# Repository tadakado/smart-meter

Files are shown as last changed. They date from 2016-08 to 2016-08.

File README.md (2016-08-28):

# Smart meter board by ADE7816

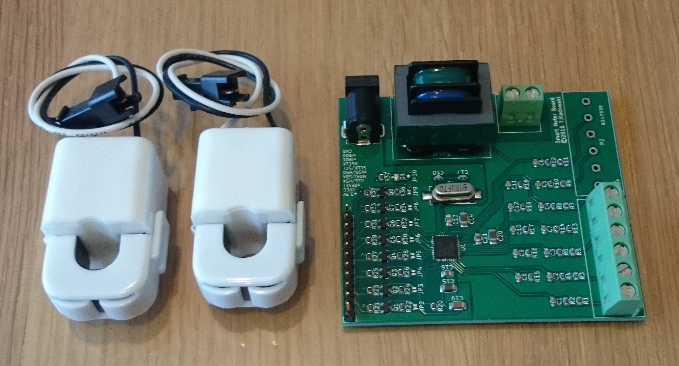
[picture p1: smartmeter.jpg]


## Description (in Japanese)
アナログデバイスのADE7816を用いた電力計のプロトタイプで、最大6チャンネルの測定ができます。
ここには、回路図、基板デザイン、テスト用のプログラムコードが含まれます。

## Description
This is a design of smart meter prototype.
The board can monitor 6 channels independently utilizing Analog Device ADE7816.
This repository includes a set of circuit/breatboard design and example software code.

## Contents in folders
* KiCad : Smart meter board
* Soft  : Javascript examples to control the smart meter board (with Intel Edison)
* FPGA  : Raw level data capture function for the smart meter board (Under development)

## Pin assignments of the board for communicating with an external cpu board
| Pin | Description |
| --- | --- |
| 3.3V | 3.3V input for the board |
| LVCC | Reference VCC of cpu board (could be 1.8V) |
| nRESET | Reset ADE7816 (active low) |
| nSS/HSA  | Select input for SPI / Port active output for HSDC (active low) |
| MOSI/SDA | Data input for SPI / Data inout for I2C |
| MISO/HSD | Data output for SPI / Data output for HSDC |
| SCLK/SCL | Clock input for SPI / Clock input for I2C |
| HSCLK | Clock output for HSDC |
| nIRQ1 | Interrupt request output (active low) |
| nIRQ0 | Interrupt request output (active low) |
| GND | Ground |

Note: LVCC is designed for a cpu board system with lower voltage such as 1.8V.
If you use 3.3V system, you can skip level converters.
For such case, use JP2-9 and remove R21-36 & Q1-8.

## Protocols of the interface
You can chose I2C or SPI to control ADE7816.
HSDC is for capturing raw level data, such as AC voltage and currents.
Due to the pin assignment, I2C and HSDC works together.
For more details, see the AD7816 manual.

## Sensor devices
Voltage and current sensing trans used in the board are
* VT2401-A01 http://growwill.co.jp/products/ep/trans/vt/#vt2401-a01
* CTL-10-CLS http://www.u-rd.com/products/CTL-10-CLS.html

If you use another sensors, you may change values of resistors.

----------
CC BY 4.0 Tadashi Kadowaki (tadakado@gmail.com)  
Licensed under a Creative Commons Attribution 4.0  
https://creativecommons.org/licenses/by/4.0/

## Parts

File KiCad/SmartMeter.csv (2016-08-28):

Reference | Value | Footprint | Datasheet
C18 | 20pF | Capacitors_SMD:C_0603_HandSoldering
C17 | 20pF | Capacitors_SMD:C_0603_HandSoldering
C21 | 0.1uF | Capacitors_SMD:C_0805_HandSoldering
C20 | 4.7uF | Capacitors_SMD:C_1206_HandSoldering
C11 | 0.22uF | Capacitors_SMD:C_0805_HandSoldering
C16 | 0.22uF | Capacitors_SMD:C_0805_HandSoldering
C15 | 4.7uF | Capacitors_SMD:C_1206_HandSoldering
C19 | 1uF | Capacitors_SMD:C_1206_HandSoldering
R20 | 10K | Resistors_SMD:R_0805_HandSoldering
Y1 | 16.384MHz | Crystals_Oscillators_SMD:Q_49U3HMS
R19 | 1K | Resistors_SMD:R_0805_HandSoldering
C14 | 22nF | Capacitors_SMD:C_0603_HandSoldering
R18 | 1K | Resistors_SMD:R_0805_HandSoldering
C12 | 22nF | Capacitors_SMD:C_0603_HandSoldering
R17 | 1K | Resistors_SMD:R_0805_HandSoldering
C10 | 22nF | Capacitors_SMD:C_0603_HandSoldering
R16 | 1K | Resistors_SMD:R_0805_HandSoldering
C9 | 22nF | Capacitors_SMD:C_0603_HandSoldering
R15 | 1K | Resistors_SMD:R_0805_HandSoldering
C8 | 22nF | Capacitors_SMD:C_0603_HandSoldering
R7 | 1K | Resistors_SMD:R_0805_HandSoldering
C1 | 22nF | Capacitors_SMD:C_0603_HandSoldering
R13 | 1K | Resistors_SMD:R_0805_HandSoldering
C7 | 22nF | Capacitors_SMD:C_0603_HandSoldering
R14 | 100 | Resistors_SMD:R_0805_HandSoldering
R1 | 33 | Resistors_SMD:R_0805_HandSoldering
R8 | 1K | Resistors_SMD:R_0805_HandSoldering
C2 | 22nF | Capacitors_SMD:C_0603_HandSoldering
R9 | 1K | Resistors_SMD:R_0805_HandSoldering
C3 | 22nF | Capacitors_SMD:C_0603_HandSoldering
R10 | 1K | Resistors_SMD:R_0805_HandSoldering
C4 | 22nF | Capacitors_SMD:C_0603_HandSoldering
R11 | 1K | Resistors_SMD:R_0805_HandSoldering
C5 | 22nF | Capacitors_SMD:C_0603_HandSoldering
R12 | 1K | Resistors_SMD:R_0805_HandSoldering
C6 | 22nF | Capacitors_SMD:C_0603_HandSoldering
T1 | TRANSFO | ADE7816:VT2401-A01
JP1 | Jumper_NC_Small | ADE7816:JP
P1 | CONN_01X06 | ADE7816:XW4E-06C1-S1
R2 | 33 | Resistors_SMD:R_0805_HandSoldering
R3 | 33 | Resistors_SMD:R_0805_HandSoldering
R4 | 33 | Resistors_SMD:R_0805_HandSoldering
R5 | 33 | Resistors_SMD:R_0805_HandSoldering
R6 | 33 | Resistors_SMD:R_0805_HandSoldering
P2 | CONN_01X06 | ADE7816:XW4E-06C1-S1
P3 | CONN_01X02 | ADE7816:XW4E-02C1-S1
C13 | 4.7uF | Capacitors_SMD:C_1206_HandSoldering
U1 | ADE7816 | ADE7816:QFN-40-1EP_6x6mm_Pitch0.5mm_HandSoldering | DOCUMENTATION
P4 | HEAT SINK | Wire_Pads:SolderWirePad_single_1-2mmDrill
P7 | Power
CON1 | BARREL_JACK
P5 | SPI
P6 | Extra
Q1 | BSS138 | SOT-23
R21 | 10K
R26 | 10K
Q2 | BSS138 | SOT-23
R22 | 10K
R27 | 10K
Q3 | BSS138 | SOT-23
R23 | 10K
R28 | 10K
Q4 | BSS138 | SOT-23
R24 | 10K
R29 | 10K
Q5 | BSS138 | SOT-23
R25 | 10K
R30 | 10K
JP2 | Jumper_NO_Small
JP3 | Jumper_NO_Small
JP4 | Jumper_NO_Small
JP5 | Jumper_NO_Small
JP6 | Jumper_NO_Small

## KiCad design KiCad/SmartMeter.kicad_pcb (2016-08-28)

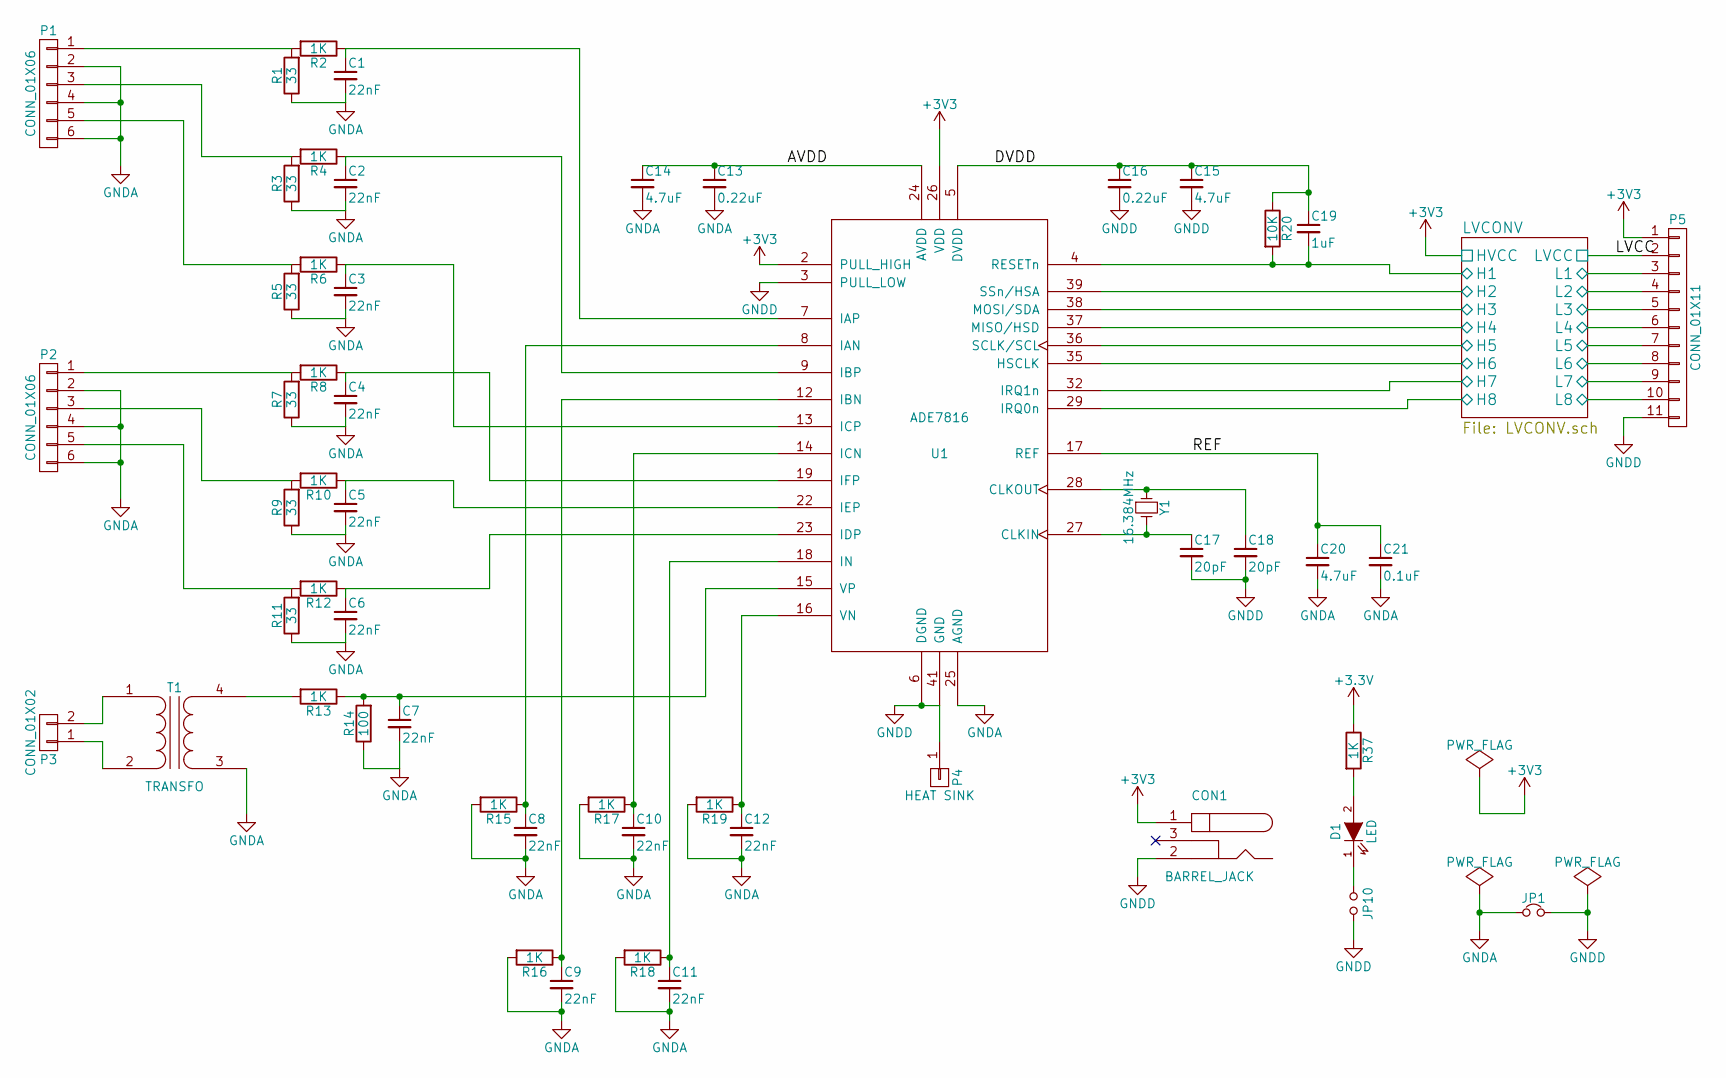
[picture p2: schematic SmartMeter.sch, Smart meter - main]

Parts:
C1, C2, C3, C4, C5, C6, C7, C8, C9, C10, C11, C12: 22nF; C_0603
C13, C16: 0.22uF; C_0805
C14, C15, C20: 4.7uF; C_1206
C17, C18: 20pF; C_0603
C19: 1uF; C_1206
C21: 0.1uF; C_0805
CON1: BARREL_JACK; DC-Jack
D1: LED; LED-0603
JP1: Jumper_NC_Small; Jumper_Close
JP10: Jumper_NO_Small; Jumper
P1, P2: CONN_01X06; XW4E-06C1-S1
P3: CONN_01X02; XW4E-02C1-S1
P4: HEAT SINK; SolderWirePad_single_1-2mmDrill
P5: CONN_01X11; Pin_Header_Straight_1x11
R1, R3, R5, R7, R9, R11: 33; R_0603
R2, R4, R6, R8, R10, R12, R13, R15, R16, R17, R18, R19, R37: 1K; R_0603
R14: 100; R_0603
R20: 10K; R_0603
T1: TRANSFO; VT2401-A01
U1: ADE7816; QFN-40-1EP_6x6mm_Pitch0.5mm
Y1: 16.384MHz; Q_49U3HMS

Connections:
+3V3: CON1.1, P5.1, R37.1, U1.2 (PULL_HIGH), U1.26 (VDD); also elsewhere on the board
/AVDD: C13.1, C14.1, U1.24 (AVDD)
/DVDD: C15.1, C16.1, C19.1, R20.1, U1.5 (DVDD)
/LVCONV/H1: C19.2, R20.2, U1.4 (RESETn); also elsewhere on the board
/LVCONV/H2: U1.39 (SSn/HSA); also elsewhere on the board
/LVCONV/H3: U1.38 (MOSI/SDA); also elsewhere on the board
/LVCONV/H4: U1.37 (MISO/HSD); also elsewhere on the board
/LVCONV/H5: U1.36 (SCLK/SCL); also elsewhere on the board
/LVCONV/H6: U1.35 (HSCLK); also elsewhere on the board
/LVCONV/H7: U1.32 (IRQ1n); also elsewhere on the board
/LVCONV/H8: U1.29 (IRQ0n); also elsewhere on the board
/LVCONV/L1: P5.3; also elsewhere on the board
/LVCONV/L2: P5.4; also elsewhere on the board
/LVCONV/L3: P5.5; also elsewhere on the board
/LVCONV/L4: P5.6; also elsewhere on the board
/LVCONV/L5: P5.7; also elsewhere on the board
/LVCONV/L6: P5.8; also elsewhere on the board
/LVCONV/L7: P5.9; also elsewhere on the board
/LVCONV/L8: P5.10; also elsewhere on the board
/LVCONV/LVCC: P5.2; also elsewhere on the board
/REF: C20.1, C21.1, U1.17 (REF)
GNDA: C1.2, C2.2, C3.2, C4.2, C5.2, C6.2, C7.2, C8.2, C9.2, C10.2, C11.2, C12.2, C13.2, C14.2, C20.2, C21.2, JP1.1, P1.2, P1.4, P1.6, P2.2, P2.4, P2.6, R1.1, R3.1, R5.1, R7.1, R9.1, R11.1, R14.1, R15.2, R16.2, R17.2, R18.2, R19.2, T1.3 (SA), U1.25 (AGND)
GNDD: C15.2, C16.2, C17.2, C18.2, CON1.2, JP1.2, JP10.2, P4.1, P5.11, U1.3 (PULL_LOW), U1.6 (DGND), U1.41 (GND)
unnamed: C1.1, R2.1, U1.7 (IAP)
unnamed: C2.1, R4.1, U1.9 (IBP)
unnamed: C3.1, R6.1, U1.13 (ICP)
unnamed: C4.1, R8.1, U1.19 (IFP)
unnamed: C5.1, R10.1, U1.22 (IEP)
unnamed: C6.1, R12.1, U1.23 (IDP)
unnamed: C7.1, R13.1, R14.2, U1.15 (VP)
unnamed: C8.1, R15.1, U1.8 (IAN)
unnamed: C9.1, R16.1, U1.12 (IBN)
unnamed: C10.1, R17.1, U1.14 (ICN)
unnamed: C11.1, R18.1, U1.18 (IN)
unnamed: C12.1, R19.1, U1.16 (VN)
unnamed: C17.1, U1.27 (CLKIN), Y1.2
unnamed: C18.1, U1.28 (CLKOUT), Y1.1
unnamed: D1.1 (K), JP10.1
unnamed: D1.2 (A), R37.2
unnamed: P1.1, R1.2, R2.2
unnamed: P1.3, R3.2, R4.2
unnamed: P1.5, R5.2, R6.2
unnamed: P2.1, R7.2, R8.2
unnamed: P2.3, R9.2, R10.2
unnamed: P2.5, R11.2, R12.2
unnamed: P3.1, T1.2 (AB)
unnamed: P3.2, T1.1 (AA)
unnamed: R13.2, T1.4 (SB)

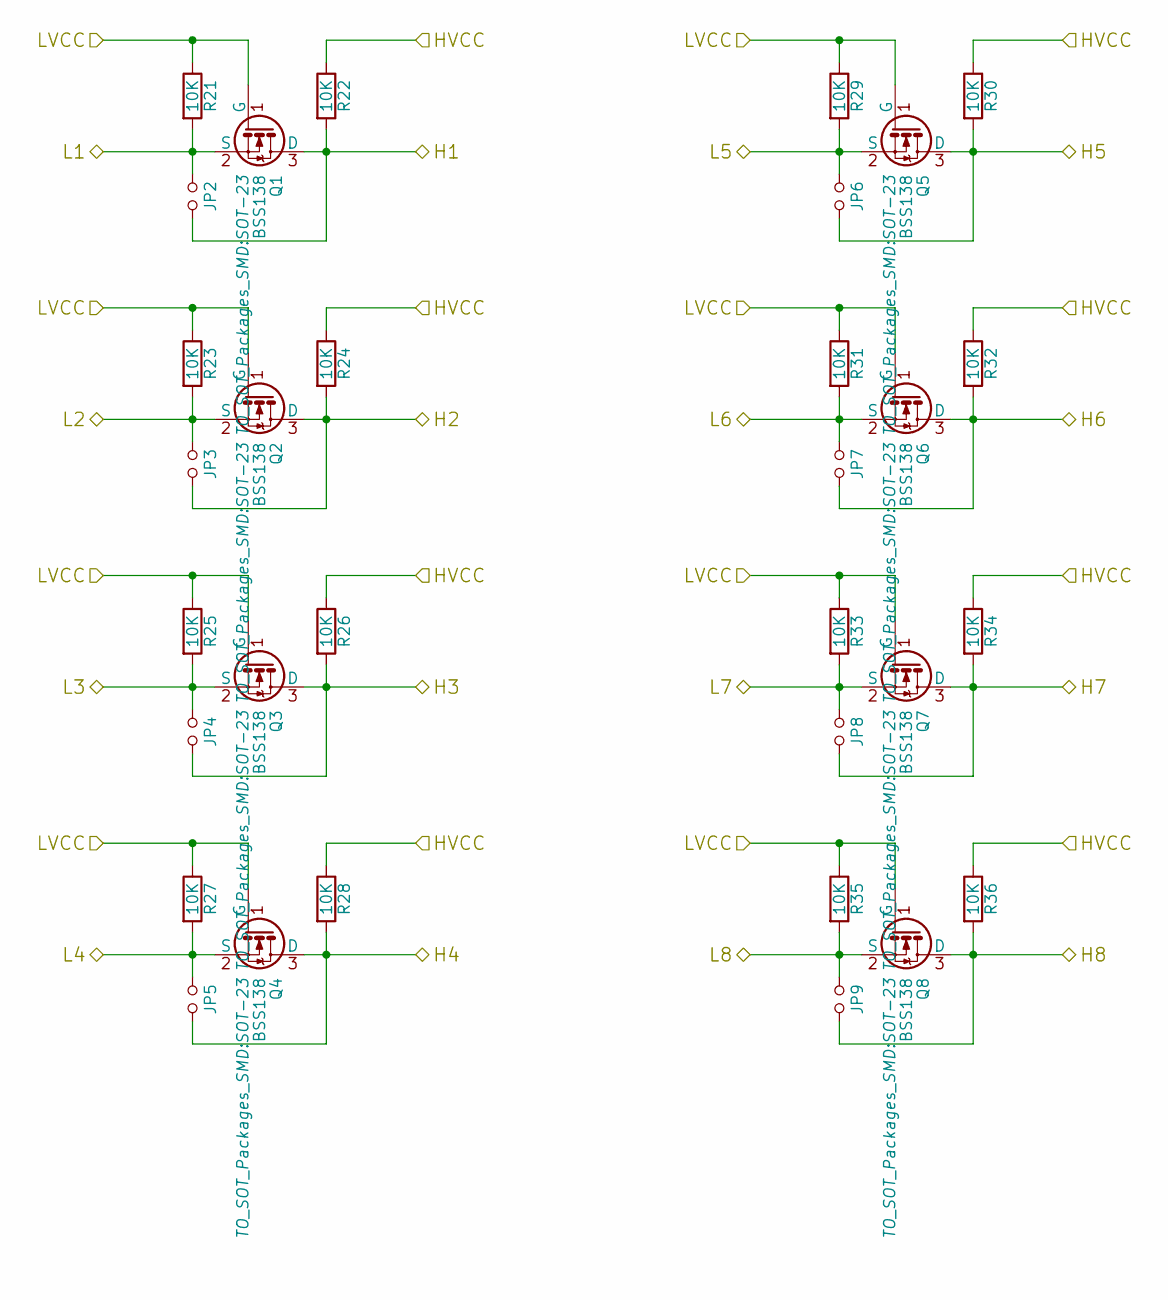
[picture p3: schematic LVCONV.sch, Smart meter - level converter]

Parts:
JP2, JP3, JP4, JP5, JP6, JP7, JP8, JP9: Jumper_NO_Small; Jumper
Q1, Q2, Q3, Q4, Q5, Q6, Q7, Q8: BSS138; SOT-23
R21, R22, R23, R24, R25, R26, R27, R28, R29, R30, R31, R32, R33, R34, R35, R36: 10K; R_0603

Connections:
+3V3: R22.1, R24.1, R26.1, R28.1, R30.1, R32.1, R34.1, R36.1; also elsewhere on the board
/LVCONV/H1: JP2.2, Q1.3 (D), R22.2; also elsewhere on the board
/LVCONV/H2: JP3.2, Q2.3 (D), R24.2; also elsewhere on the board
/LVCONV/H3: JP4.2, Q3.3 (D), R26.2; also elsewhere on the board
/LVCONV/H4: JP5.2, Q4.3 (D), R28.2; also elsewhere on the board
/LVCONV/H5: JP6.2, Q5.3 (D), R30.2; also elsewhere on the board
/LVCONV/H6: JP7.2, Q6.3 (D), R32.2; also elsewhere on the board
/LVCONV/H7: JP8.2, Q7.3 (D), R34.2; also elsewhere on the board
/LVCONV/H8: JP9.2, Q8.3 (D), R36.2; also elsewhere on the board
/LVCONV/L1: JP2.1, Q1.2 (S), R21.2; also elsewhere on the board
/LVCONV/L2: JP3.1, Q2.2 (S), R23.2; also elsewhere on the board
/LVCONV/L3: JP4.1, Q3.2 (S), R25.2; also elsewhere on the board
/LVCONV/L4: JP5.1, Q4.2 (S), R27.2; also elsewhere on the board
/LVCONV/L5: JP6.1, Q5.2 (S), R29.2; also elsewhere on the board
/LVCONV/L6: JP7.1, Q6.2 (S), R31.2; also elsewhere on the board
/LVCONV/L7: JP8.1, Q7.2 (S), R33.2; also elsewhere on the board
/LVCONV/L8: JP9.1, Q8.2 (S), R35.2; also elsewhere on the board
/LVCONV/LVCC: Q1.1 (G), Q2.1 (G), Q3.1 (G), Q4.1 (G), Q5.1 (G), Q6.1 (G), Q7.1 (G), Q8.1 (G), R21.1, R23.1, R25.1, R27.1, R29.1, R31.1, R33.1, R35.1; also elsewhere on the board

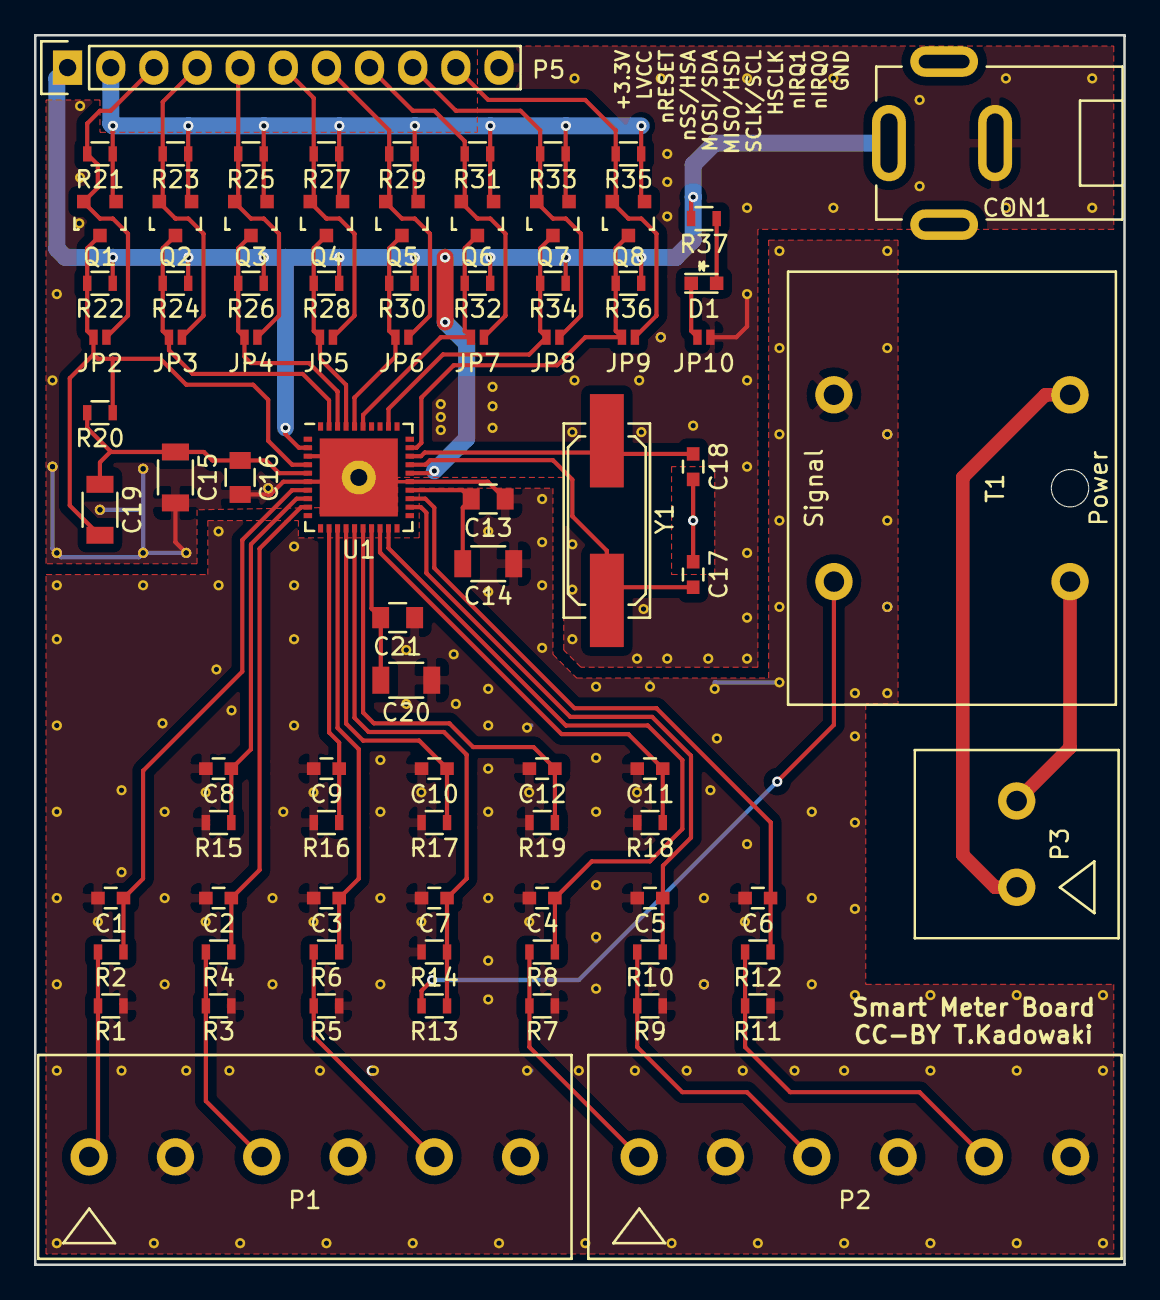
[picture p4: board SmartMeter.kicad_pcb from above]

Board: 2 copper layers, 64.1 x 72.4 mm, 86 parts (0 on the bottom side), 48 nets.

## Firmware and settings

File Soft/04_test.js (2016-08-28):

//!/usr/bin/node

// POWER UP THE ADE7816 (SEE POWER AND GROUND SECTION)

// SET AND LOCK COMMUNICATION MODE (SEE COMMUNICATION SECTION)

// WRITE REQUIRED REGISTER DEFAULTS
// WTHR1 = 0x000002
// WTHR0 = 0x000000
// VARTHR1 = 0x000002
// VARTHR0 = 0x000000
// PCF_A_COEFF = 0x400CA4 (50Hz)
// PCF_B_COEFF = 0x400CA4 (50Hz)
// PCF_C_COEFF = 0x400CA4 (50Hz)
// PCF_D_COEFF = 0x400CA4 (50Hz)
// PCF_E_COEFF = 0x400CA4 (50Hz)
// PCF_F_COEFF = 0x400CA4 (50Hz)
// DICOEFF = 0xFFF8000

// CONFIGURE METER SPECIFIC INTERRUPTS, POWER QUALITY FEATURES, AND CALIBRATE
// (SEE THE INTERRUPTS, POWER QUALITY FEATURES, AND ENERGY CALIBRATION SECTIONS)

// NOTE THAT THE FINAL REGISTER SHOULD BE WRITTEN 3 TIMES TO CLEAR THE BUFFER
// (SEE STARTING AND STOPPING THE DSP SECTION)

// ENABLE THE ENERGY METERING DSP (SEE STARTING AND STOPPING THE DSP SECTION)

const VGAIN = 0x4380
const IAGAIN = 0x4381
const IBGAIN = 0x4382
const ICGAIN = 0x4383
const IDGAIN = 0x4384
const IEGAIN = 0x4385
const IFGAIN = 0x4386
const DICOEFF = 0x4388
const HPFDIS = 0x4389
const VRMSOS = 0x438A
const IARMSOS = 0x438B
const IBRMSOS = 0x438C
const ICRMSOS = 0x438D
const IDRMSOS = 0x438E
const IERMSOS = 0x438F
const IFRMSOS = 0x4390
const AWGAIN = 0x4391
const AWATTOS = 0x4392
const BWGAIN = 0x4393
const BWATTOS = 0x4394
const CWGAIN = 0x4395
const CWATTOS = 0x4396
const DWGAIN = 0x4397
const DWATTOS = 0x4398
const EWGAIN = 0x4399
const EWATTOS = 0x439A
const FWGAIN = 0x439B
const FWATTOS = 0x439C
const AVARGAIN = 0x439D
const AVAROS = 0x439E
const BVARGAIN = 0x439F
const BVAROS = 0x43A0
const CVARGAIN = 0x43A1
const CVAROS = 0x43A2
const DVARGAIN = 0x43A3
const DVAROS = 0x43A4
const EVARGAIN = 0x43A5
const EVAROS = 0x43A6
const FVARGAIN = 0x43A7
const FVAROS = 0x43A8
const WTHR1 = 0x43AB
const WTHR0 = 0x43AC
const VARTHR1 = 0x43AD
const VARTHR0 = 0x43AE
const APNOLOAD = 0x43AF

const VARNOLOAD = 0x43B0
const PCF_A_COEFF = 0x43B1
const PCF_B_COEFF  = 0x43B2
const PCF_C_COEFF  = 0x43B3
const PCF_D_COEFF  = 0x43B4
const PCF_E_COEFF  = 0x43B5
const PCF_F_COEFF  = 0x43B6
const VRMS = 0x43C0
const IARMS = 0x43C1
const IBRMS = 0x43C2
const ICRMS = 0x43C3
const IDRMS = 0x43C4
const IERMS = 0x43C5
const IFRMS  = 0x43C6

const RUN = 0xE228

const AWATTHR = 0xE400
const BWATTHR = 0xE401
const CWATTHR = 0xE402
const DWATTHR = 0xE403
const EWATTHR = 0xE404
const FWATTHR = 0xE405
const AVARHR = 0xE406
const BVARHR = 0xE407
const CVARHR = 0xE408
const DVARHR = 0xE409
const EVARHR = 0xE40A
const FVARHR = 0xE40B

const VPEAK = 0xE501
const STATUS0 = 0xE502
const STATUS1 = 0xE503
const OILVL = 0xE507
const OVLVL = 0xE508
const SAGLVL = 0xE509
const MASK0 = 0xE50A
const MASK1 = 0xE50B
const IAWV_IDWV = 0xE50C
const IBWV_IEWV = 0xE50D
const ICWV_IFWV = 0xE50E
const VWV = 0xE510
const CHECKSUM = 0xE51F
const CHSTATUS = 0xE600
const ANGLE0 = 0xE601
const ANGLE1 = 0xE602
const ANGLE2 = 0xE603
const PERIOD = 0xE607
const CHNOLOAD = 0xE608
const LINECYC = 0xE60C
const ZXTOUT = 0xE60D
const COMPMODE = 0xE60E
const GAIN = 0xE60F
const CHSIGN = 0xE617
const CONFIG = 0xE618
const MMODE = 0xE700
const ACCMODE = 0xE701
const LCYCMODE = 0xE702
const PEAKCYC = 0xE703
const SAGCYC = 0xE704
const HSDC_CFG = 0xE706
const VERSION  = 0xE707
const SPISELECT = 0xEBFF
const CONFIG2  = 0xEC01

function parseBytes(v, n, p) {
  var a = new Array(n)
  for(var i = 1; i <= n; i++) {
    var shift = (i-1) * 8
    a[n-i] = (v >>> shift) & 0xFF
  }
  // padding 'ZPSE' or 'SE' for 24 bit registers with 32 bit communication
  if (n == 4 && p == 'ZPSE' && a[1] & 0x80) a[0] = 0x0F
  if (n == 4 && p == 'SE' && a[1] & 0x80) a[0] = 0xFF
  return a
}

function i2cWriteSeq(addr, buf) {
  var a = new Array(parseBytes(addr, 2), buf)
  return Buffer(Array.prototype.concat.apply([], a))
}

function i2cReadSeq(addr) {
  var a = new Array(parseBytes(addr, 2))
  return Buffer(Array.prototype.concat.apply([], a))
}

function i2cWrite(addr, data, n, p) {
  // i2c, bufIn and BufOut are global variables
  bufIn = i2cWriteSeq(addr, parseBytes(data, n, p))
  bufOut = i2c.write(bufIn)
  return bufOut
}

function i2cWriteRepeat() {
  // i2c, bufIn and BufOut are global variables
  bufOut = i2c.write(bufIn)
  return bufOut
}

function i2cRead(addr, n) {
  // i2c, bufIn and BufOut are global variables
  bufIn = i2cReadSeq(addr)
  i2c.write(bufIn)
  bufOut = i2c.read(n)
  return bufOut
}

var m = require('mraa')
var i2c = new m.I2c(0)
var bufIn = new Buffer(0)
var bufOut = new Buffer(0)

i2c.address(0x38)
i2c.frequency(100000)

// Soft reset
//i2cWrite(CONFIG, 0x0080, 2)
//i2cWrite(CONFIG, 0x0000, 2)

// Setup registers
i2cWrite(WTHR1, 0x000002, 4)
i2cWrite(WTHR0, 0x000000, 4)
i2cWrite(VARTHR1, 0x000002, 4)
i2cWrite(VARTHR0, 0x000000, 4)
i2cWrite(PCF_A_COEFF, 0x400CA4, 4, 'ZPSE')
i2cWrite(PCF_B_COEFF, 0x400CA4, 4, 'ZPSE')
i2cWrite(PCF_C_COEFF, 0x400CA4, 4, 'ZPSE')
i2cWrite(PCF_D_COEFF, 0x400CA4, 4, 'ZPSE')
i2cWrite(PCF_E_COEFF, 0x400CA4, 4, 'ZPSE')
i2cWrite(PCF_F_COEFF, 0x400CA4, 4, 'ZPSE')
i2cWrite(DICOEFF, 0xFF8000, 4, 'ZPSE')

// HSDC output
i2cWrite(HSDC_CFG, 0x08, 1) // 0x08 or 0x09 or 0x0C or 0x0D
i2cWrite(CONFIG, 0x0040, 2)

// accumulation mode
v = i2cRead(LCYCMODE, 1)
v[0] = v[0] & 0xBF
i2cWrite(LCYCMODE, v, 1)

// Repeat the last command 3 times
i2cWriteRepeat()
i2cWriteRepeat()

// RUN DSP
i2cWrite(RUN, 0x0001, 2)

//
var id = setInterval(function() {
    console.log('--------------------')
    voltage = i2cRead(VWV, 4)
    console.log('Voltage: ' + voltage.readInt32BE(0) + '(' + voltage.toString('hex') + ')')
    //    i2cWrite(COMPMODE, 0x01FF, 2)
    current = i2cRead(IAWV_IDWV, 4)
    console.log('Current A: ' + current.readInt32BE(0) + '(' + current.toString('hex') + ')')
    current = i2cRead(IBWV_IEWV, 4)
    console.log('Current B: ' + current.readInt32BE(0) + '(' + current.toString('hex') + ')')
    current = i2cRead(ICWV_IFWV, 4)
    console.log('Current C: ' + current.readInt32BE(0) + '(' + current.toString('hex') + ')')
    //    i2cWrite(COMPMODE, 0x41FF, 2)
    current = i2cRead(IAWV_IDWV, 4)
    console.log('Current D: ' + current.readInt32BE(0) + '(' + current.toString('hex') + ')')
    current = i2cRead(IBWV_IEWV, 4)
    console.log('Current E: ' + current.readInt32BE(0) + '(' + current.toString('hex') + ')')
    current = i2cRead(ICWV_IFWV, 4)
    console.log('Current F: ' + current.readInt32BE(0) + '(' + current.toString('hex') + ')')
    console.log('Energy A: ' + i2cRead(AWATTHR, 4).readInt32BE(0))
    console.log('Energy B: ' + i2cRead(BWATTHR, 4).readInt32BE(0))
    console.log('Energy C: ' + i2cRead(CWATTHR, 4).readInt32BE(0))
    console.log('Energy D: ' + i2cRead(DWATTHR, 4).readInt32BE(0))
    console.log('Energy E: ' + i2cRead(EWATTHR, 4).readInt32BE(0))
    console.log('Energy F: ' + i2cRead(FWATTHR, 4).readInt32BE(0))
}, 1000)

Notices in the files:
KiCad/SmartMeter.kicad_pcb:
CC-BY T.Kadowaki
